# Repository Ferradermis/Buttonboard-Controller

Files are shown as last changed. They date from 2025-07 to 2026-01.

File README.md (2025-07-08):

# FRC Custom Operator Control Board
## Overview
This project provides a reusable hardware and software ecosystem for rapidly developing game-specific control surfaces for FIRST Robotics Competition (FRC) teams. Inspired by successful world-class teams who have leveraged custom control boards for years, our solution enables any team to quickly create and deploy specialized operator interfaces tailored to each year's unique game challenges.

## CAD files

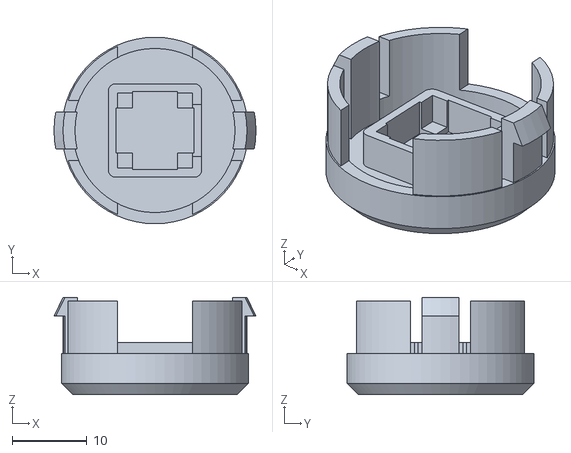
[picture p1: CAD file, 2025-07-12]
button/buttonface thicker.stl
27.0 x 24.9 x 13.0

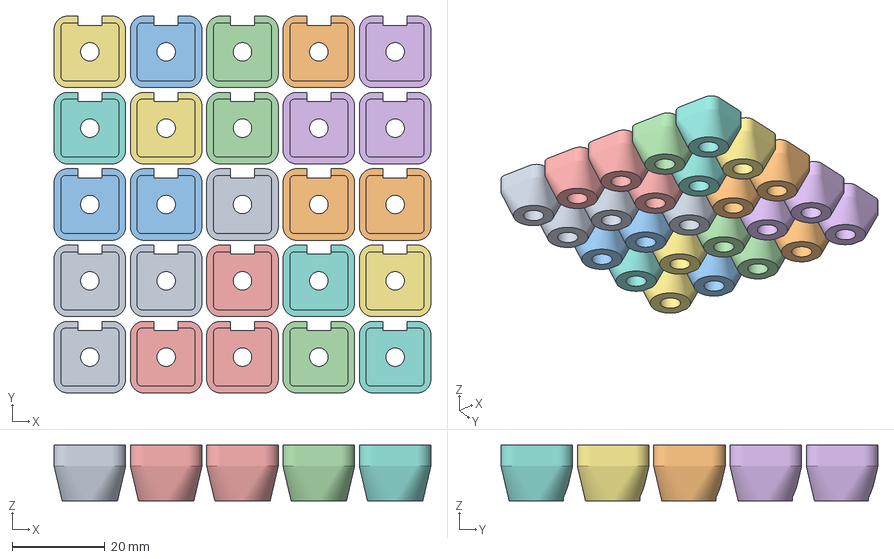
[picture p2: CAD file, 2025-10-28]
button2/ledcap.3mf
81.5 x 81.5 x 12.0 mm
ledcap.stl x 25

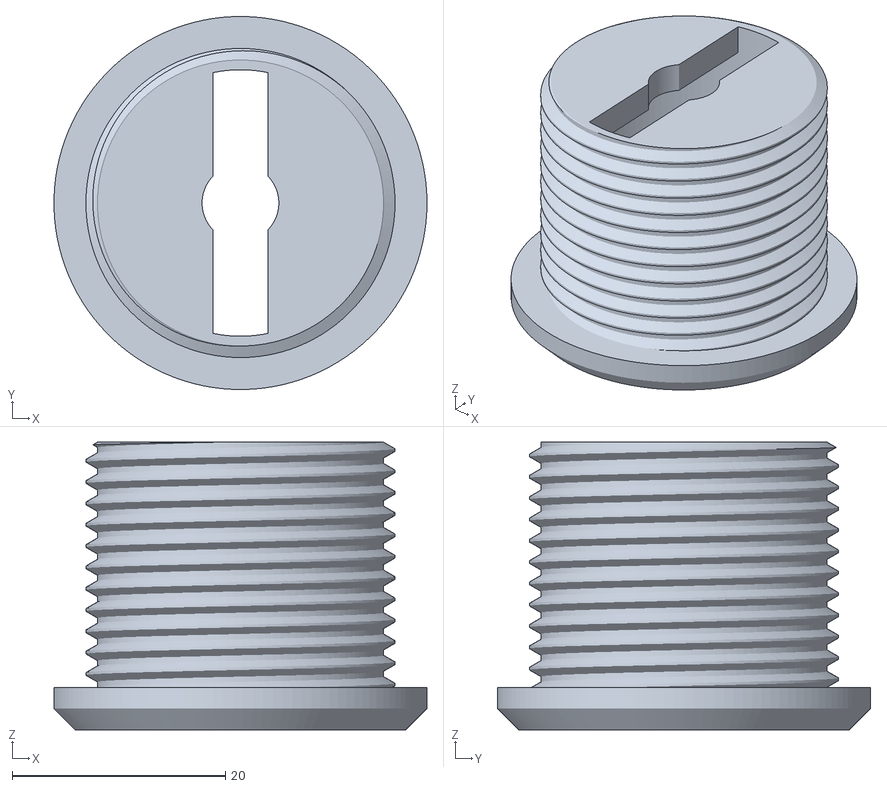
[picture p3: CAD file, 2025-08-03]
button3/housing.stl
35.0 x 35.0 x 27.0

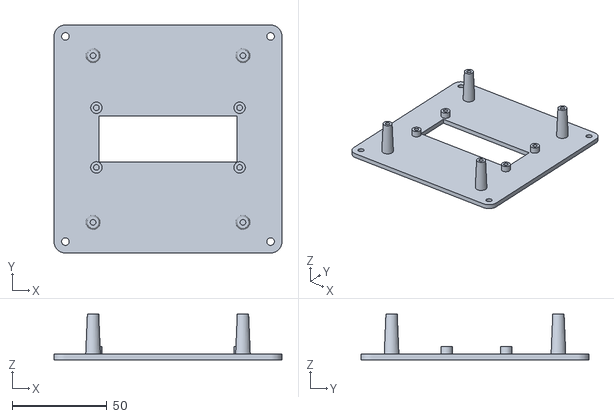
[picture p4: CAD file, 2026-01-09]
pcb chassis/chassis.stl
120.0 x 120.0 x 24.0

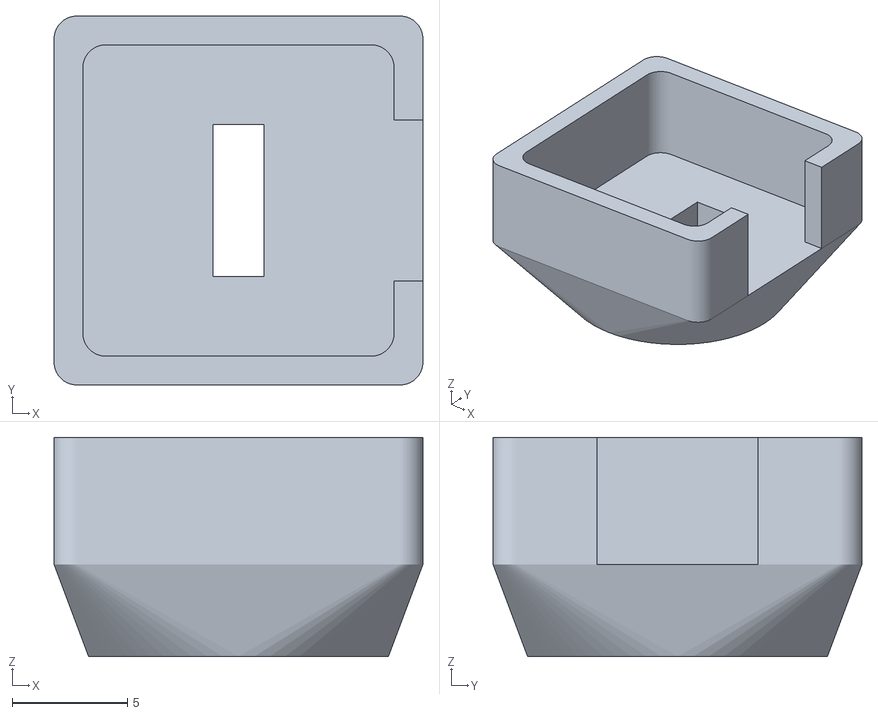
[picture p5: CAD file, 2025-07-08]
button/cap.stl
16.0 x 16.0 x 9.50

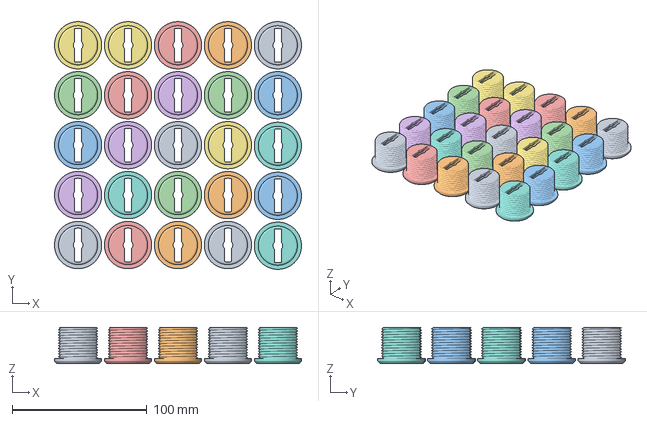
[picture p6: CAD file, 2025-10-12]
button2/housing.3mf
183.0 x 183.5 x 27.0 mm
housing.stl x 25

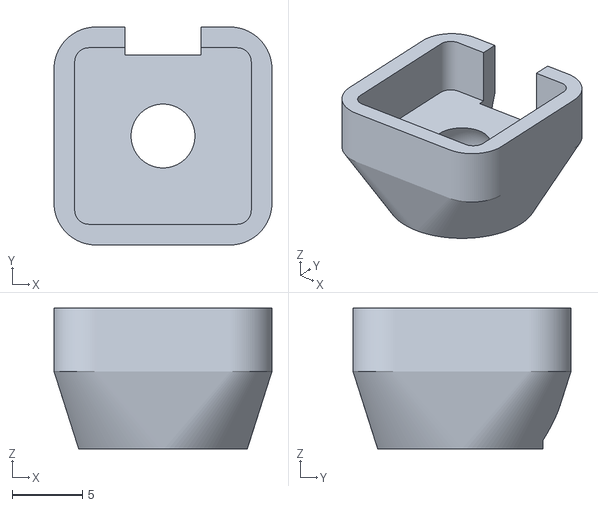
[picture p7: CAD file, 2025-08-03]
button3/ledcap.stl
15.5 x 15.5 x 10.0

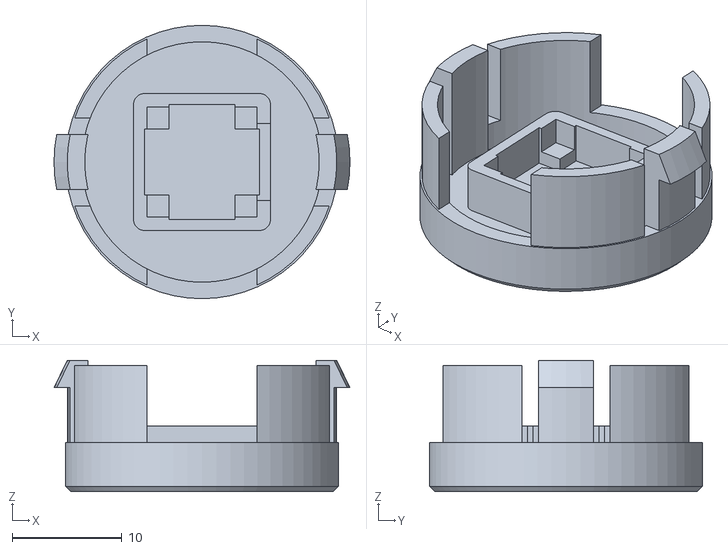
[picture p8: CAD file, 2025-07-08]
button/buttonface.stl
27.0 x 24.9 x 12.0

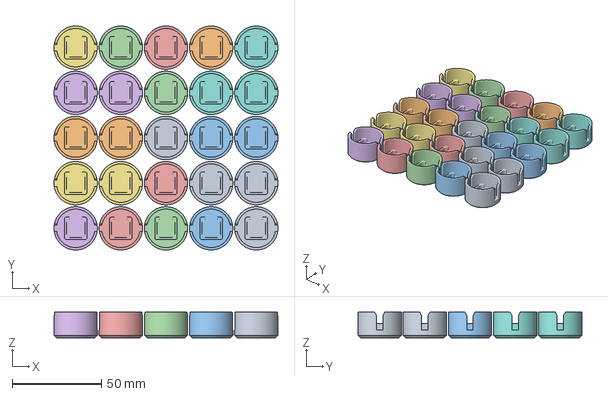
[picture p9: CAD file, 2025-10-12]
button2/button.3mf
125.2 x 125.2 x 14.5 mm
button.stl x 25

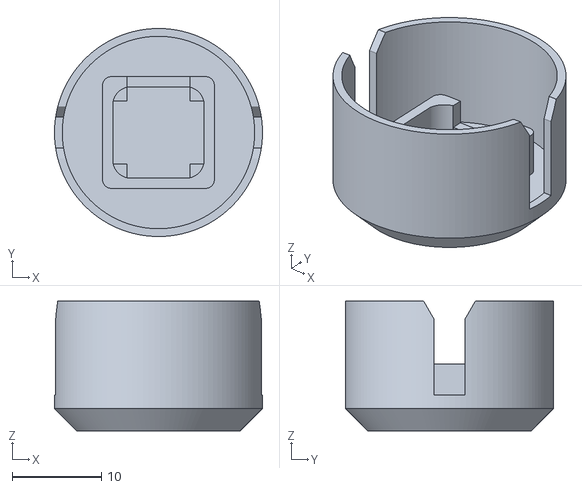
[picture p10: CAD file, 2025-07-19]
button3/button.stl
23.2 x 23.2 x 14.5

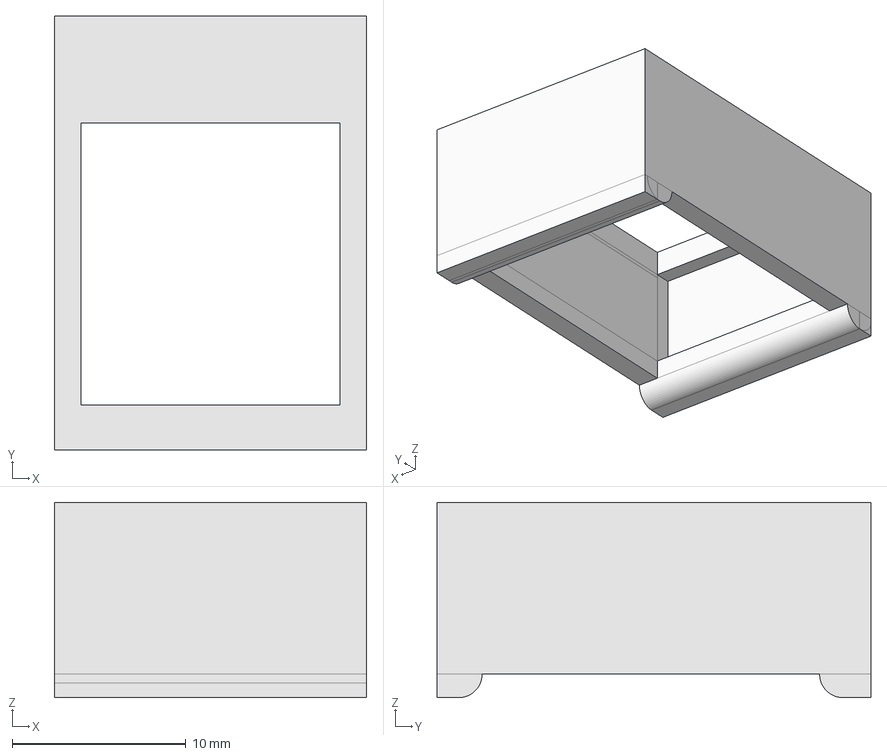
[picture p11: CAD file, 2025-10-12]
button2/rj45_keystone_receiver.step
18.0 x 25.0 x 11.2 mm

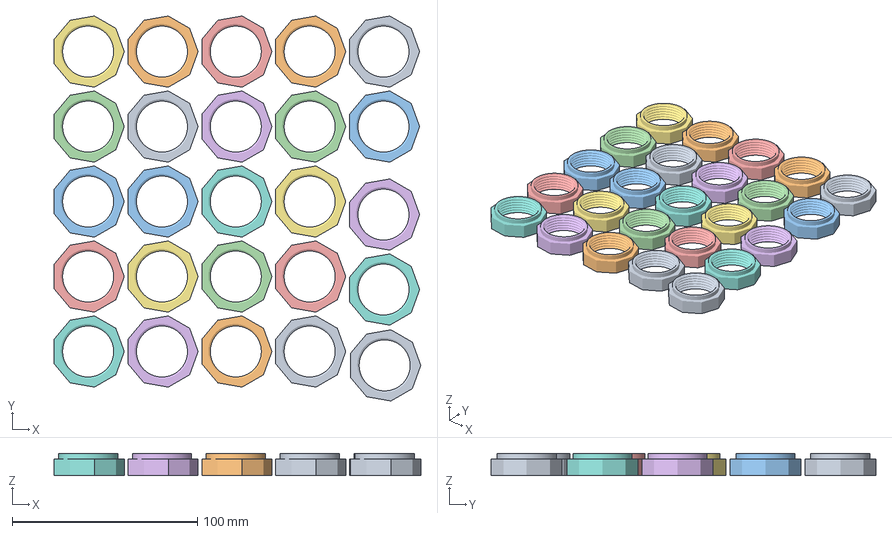
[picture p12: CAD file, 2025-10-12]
button2/nut.3mf
197.8 x 207.7 x 12.0 mm
nut.stl 1
nut.stl 3
nut.stl 4
nut.stl 5
nut.stl 6
nut.stl 8
nut.stl 9
nut.stl 10
nut.stl 11
nut.stl 12
nut.stl 13
nut.stl 15
nut.stl 16
nut.stl 17
nut.stl 18
nut.stl 19
nut.stl 20
nut.stl 21
nut.stl 22
nut.stl 24
nut.stl 25
nut.stl 26
nut.stl 27
nut.stl 31
nut.stl 33

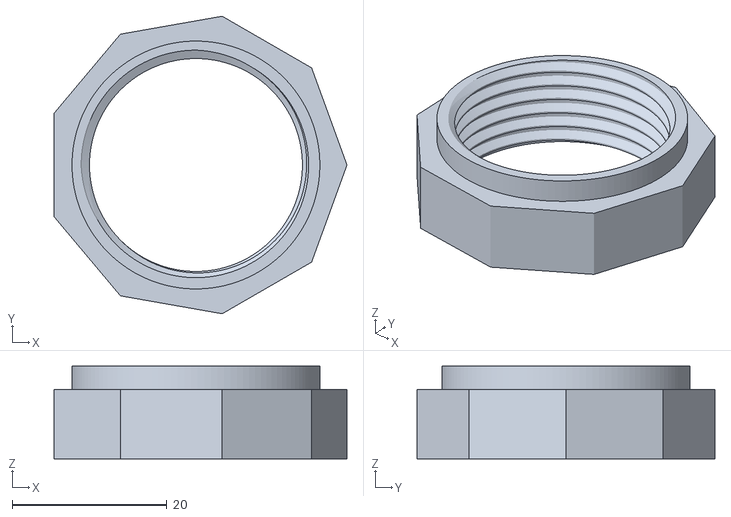
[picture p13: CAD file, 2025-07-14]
button3/nut.stl
37.8 x 38.4 x 12.0

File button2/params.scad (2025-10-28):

echo("including params.scad");
include <./ISOThread.scad>
$fn=117;

//housing params (including threads)
thread_tolerance=0.25;
od_rim=35;
h_rim=4;
bevel_rim=2;
tpitch=2.0;
od_housing=29;
od_housing_minor=tpitch;
od_housing_wings=30;
id_housing=25;
h_housing=27;
w_housing_guide=2;

w_fin=1.2;
h_fin=6;

//button params
od_button=24.25;
id_button=21.50;
t_buttonface=3.5;
bevel_buttonface=1.5;
h_button=14.5;
h_button_travel=h_button+2;
w_button_guide=3.5;

//switch params
d_switch_key=6.05;
h_switch_key=3.5;
d_switch_neck=7;
d_switch_body=7.20;
d_switch_shoulder=12;



w_wire_notch=d_switch_body-2;



w_pixel_board=10.2;
w_pixel=7;
t_pixel=1;
t_pixel_unit=4.25;
w_pedestal=12.5;
h_pedestal=t_pixel_unit + 0.25;

h_nut=9;
d_nut=od_housing+10;
nut_sides=9;
h_nut_rim=3;

h_led_cap=12;
w_led_cap=w_pedestal+3;


module rcube(s,r=1){
    hull(){
        for(x=[r,s[0]-r])
            for(y=[r,s[1]-r])
                translate([x,y,0])
                    cylinder(r=r,h=s[2]);
    }
}

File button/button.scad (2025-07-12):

$fn=60;

d_button=24.95;
d_minor=24.6;

t_total=12.56;
l_tab=4;

t_bevel=1.5;
    t_face=t_bevel+1.5;
    h_face=4;
    t_shell=1.5;


main();

//cap();

//clip_shape();

module cap(){
    cap_size=16;
    cap_base_d=13;
    cap_height=9.5;
    cap_stem_height=4;
    cap_cavity_size=13.5;
    difference(){
        union(){
            hull(){
                cylinder(d=cap_base_d,h=1);
                translate([-cap_size/2,-cap_size/2,cap_stem_height])
                    rcube([16,16,cap_height-cap_stem_height]);
            }
        }
        union(){
            translate([-cap_cavity_size/2,-cap_cavity_size/2,cap_stem_height])
                    rcube([cap_cavity_size,cap_cavity_size,15]);

            //button slot
            translate([-1.1,-3.3,0])
                cube([2.2,6.6,14]);
            //notch for wires
            translate([0,-3.5,cap_stem_height])
                cube([10,7,10]);
            
        }
    }
}


module clip_shape(){
    translate([d_minor/2-1.6,.5+t_bevel])
    polygon(points=[
        [0,0],
        [1.6,0],
        [1.6,8.5],
        [2.81,8.5],
        [1.6,11],
        [0,11]

    ]);
}

module main(){
    


    difference(){
        union(){
            cylinder(d1=d_button-t_bevel*2,d2=d_button,h=t_bevel);
            translate([0,0,t_bevel])
                cylinder(d=d_button,h=h_face);
        }
        union(){
            translate([0,0,t_face])
                cylinder(d=d_button-t_shell*2,h=h_face);
        }
    }

    difference(){
        union(){
            translate([0,0,t_bevel])
                cylinder(d=d_minor,h=11);
        }
        union(){
            translate([-20,-4,4.5])
                cube([40,8,20]);

            translate([-5,-20,4.5])
                cube([10,40,20]);

            cylinder(d=d_button - 2*t_shell, h=20);
        }
    }

    pixel_holder_size=12.5;
    
    difference(){
        union(){
            translate([-pixel_holder_size/2,-pixel_holder_size/2,0])
                rcube([pixel_holder_size,pixel_holder_size,t_face+4]);
        }
        union(){
            translate([0,-3.5,4])
                cube([10,7,10]);

            translate([-5.25,-3,2.5])
                cube([10.5,6,10]);
            translate([-3,-5.25,2.5])
                cube([6,10.5,10]);
            
            translate([-5,-5,3.7])
                cube([10,10,10]);
                
        }
    }

    intersection(){
        translate([-20,-2.5,0])
            cube([40,5,40]);
        rotate_extrude(){
            clip_shape();
        }
    }
    
}

module rcube(size,r=1){
    hull(){
        for(x=[r,size[0]-r])
            for (y=[r,size[1]-r])
                translate([x,y,0])
                    cylinder(r=r,h=size[2]);
    }
            
}

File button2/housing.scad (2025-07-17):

include <./params.scad>



main();

module main(){
    difference(){
        union(){
            iso_thread(m=od_housing,l=h_housing,p=tpitch);
            cylinder(d1=od_rim-2*bevel_rim,d2=od_rim,h=bevel_rim);
            translate([0,0,bevel_rim])
                cylinder(d=od_rim,h=h_rim-bevel_rim);

            

        }
        union(){

            cylinder(d=id_housing,h=h_housing-3);

            cylinder(d=d_switch_body,h=h_housing);

            intersection(){
                cylinder(d=id_housing,h=h_housing);
                translate([-w_wire_notch/2,-od_housing/2,0])
                    cube([w_wire_notch,od_housing,h_housing]);

            }

        }
    }

    


    //button guides
    difference(){
        union(){
            intersection(){
                cylinder(d=id_housing,h=h_housing);
                translate([-od_housing/2,-w_housing_guide/2,0])
                    cube([od_housing,w_housing_guide,h_housing]);
            }
        }
        union(){
            cylinder(d=id_housing,h=4);
            translate([0,0,4])
                cylinder(d1=id_housing,d2=id_housing-2 * w_housing_guide,h=w_housing_guide);
            cylinder(d=id_housing-2 * w_housing_guide,h=h_housing);
        }
    }

}

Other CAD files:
button3/params.scad
button2/button.stl
button2/ledcap.scad
button2/ledcap.stl
button2/rj45_keystone_receiver.scad
button3/ISOThread.scad
button3/button.scad
button3/housing.scad
button3/ledcap.scad
button3/nut.scad
button3/socket.scad
pcb chassis/chassis.scad

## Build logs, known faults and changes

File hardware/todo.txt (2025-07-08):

Add ethernet jack - done
add USB port to board - done
add reset MCU pins/button - done
add USB Host port - done
instead of 4 GPIOs, add 4 more buttons (kids got to 24 FAST) - done

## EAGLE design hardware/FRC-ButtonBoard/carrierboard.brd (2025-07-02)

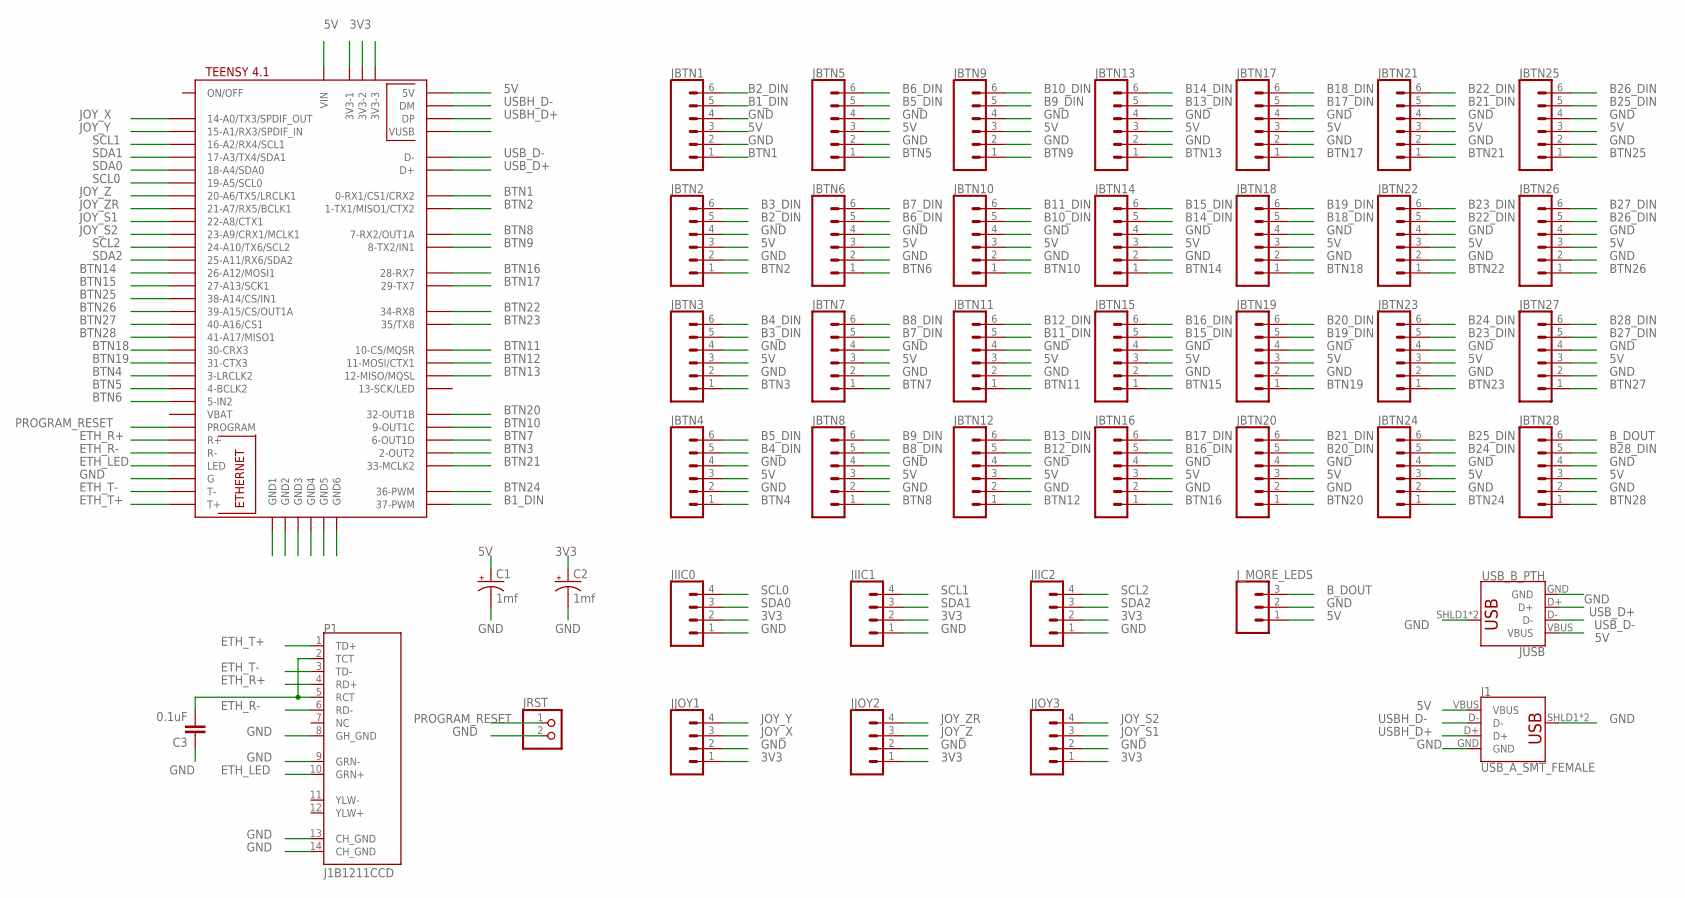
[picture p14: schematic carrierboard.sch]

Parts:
C1, C2: 1mf; CPOL-RADIAL-5MM-10MM-KIT
C3: 0.1uF; CAP-PTH-SMALL-KIT
J1: USB_A_SMT_FEMALE; USB-A-S-SILK-FEMALE
JBTN1, JBTN2, JBTN3, JBTN4, JBTN5, JBTN6, JBTN7, JBTN8, JBTN9, JBTN10, JBTN11, JBTN12, JBTN13, JBTN14, JBTN15, JBTN16, JBTN17, JBTN18, JBTN19, JBTN20, JBTN21, JBTN22, JBTN23, JBTN24, JBTN25, JBTN26, JBTN27, JBTN28: CONN_06SILK_FEMALE_PTH; 1X06
JIIC0, JIIC1, JIIC2: CONN_04POLAR; MOLEX-1X4
JJOY1, JJOY2, JJOY3: CONN_04LONGPADS; 1X04_LONGPADS
JRST: PINHD-1X2; 1X02
JUSB: USB_B_PTH; USB-B-PTH
J_MORE_LEDS: CONN_03LONGPADS; 1X03_LONGPADS
P1: J1B1211CCD
U$1: TEENSY41

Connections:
3V3: C2.+, JIIC0.2, JIIC1.2, JIIC2.2, JJOY1.1, JJOY2.1, JJOY3.1, U$1.3V3-1, U$1.3V3-2, U$1.3V3-3
5V: C1.+, J1.VBUS, JBTN1.3, JBTN2.3, JBTN3.3, JBTN4.3, JBTN5.3, JBTN6.3, JBTN7.3, JBTN8.3, JBTN9.3, JBTN10.3, JBTN11.3, JBTN12.3, JBTN13.3, JBTN14.3, JBTN15.3, JBTN16.3, JBTN17.3, JBTN18.3, JBTN19.3, JBTN20.3, JBTN21.3, JBTN22.3, JBTN23.3, JBTN24.3, JBTN25.3, JBTN26.3, JBTN27.3, JBTN28.3, JUSB.VBUS, J_MORE_LEDS.1, U$1.+5V (5V), U$1.VIN
B1_DIN: JBTN1.5, U$1.37-PWM
B2_DIN: JBTN1.6, JBTN2.5
B3_DIN: JBTN2.6, JBTN3.5
B4_DIN: JBTN3.6, JBTN4.5
B5_DIN: JBTN4.6, JBTN5.5
B6_DIN: JBTN5.6, JBTN6.5
B7_DIN: JBTN6.6, JBTN7.5
B8_DIN: JBTN7.6, JBTN8.5
B9_DIN: JBTN8.6, JBTN9.5
B10_DIN: JBTN9.6, JBTN10.5
B11_DIN: JBTN10.6, JBTN11.5
B12_DIN: JBTN11.6, JBTN12.5
B13_DIN: JBTN12.6, JBTN13.5
B14_DIN: JBTN13.6, JBTN14.5
B15_DIN: JBTN14.6, JBTN15.5
B16_DIN: JBTN15.6, JBTN16.5
B17_DIN: JBTN16.6, JBTN17.5
B18_DIN: JBTN17.6, JBTN18.5
B19_DIN: JBTN18.6, JBTN19.5
B20_DIN: JBTN19.6, JBTN20.5
B21_DIN: JBTN20.6, JBTN21.5
B22_DIN: JBTN21.6, JBTN22.5
B23_DIN: JBTN22.6, JBTN23.5
B24_DIN: JBTN23.6, JBTN24.5
B25_DIN: JBTN24.6, JBTN25.5
B26_DIN: JBTN25.6, JBTN26.5
B27_DIN: JBTN26.6, JBTN27.5
B28_DIN: JBTN27.6, JBTN28.5
BTN1: JBTN1.1, U$1.0-RX1/CS1/CRX2
BTN2: JBTN2.1, U$1.1-TX1/MISO1/CTX2
BTN3: JBTN3.1, U$1.2-OUT2
BTN4: JBTN4.1, U$1.3-LRCLK2
BTN5: JBTN5.1, U$1.4-BCLK2
BTN6: JBTN6.1, U$1.5-IN2
BTN7: JBTN7.1, U$1.6-OUT1D
BTN8: JBTN8.1, U$1.7-RX2/OUT1A
BTN9: JBTN9.1, U$1.8-TX2/IN1
BTN10: JBTN10.1, U$1.9-OUT1C
BTN11: JBTN11.1, U$1.10-CS\MQSR (10-CS/MQSR)
BTN12: JBTN12.1, U$1.11-MOSI/CTX1
BTN13: JBTN13.1, U$1.12-MISO/MQSL
BTN14: JBTN14.1, U$1.26-A12/MOSI1
BTN15: JBTN15.1, U$1.27-A13/SCK1
BTN16: JBTN16.1, U$1.28-RX7
BTN17: JBTN17.1, U$1.29-TX7
BTN18: JBTN18.1, U$1.30-CRX3
BTN19: JBTN19.1, U$1.31-CTX3
BTN20: JBTN20.1, U$1.32-OUT1B
BTN21: JBTN21.1, U$1.33-MCLK2
BTN22: JBTN22.1, U$1.34-RX8
BTN23: JBTN23.1, U$1.35-TX8 (35/TX8)
BTN24: JBTN24.1, U$1.36-PWM
BTN25: JBTN25.1, U$1.38-A14/CS/IN1
BTN26: JBTN26.1, U$1.39-A15/CS/OUT1A
BTN27: JBTN27.1, U$1.40-A16/CS1
BTN28: JBTN28.1, U$1.41-A17/MISO1
B_DOUT: JBTN28.6, J_MORE_LEDS.3
ETH_LED: P1.10 (GRN+), U$1.LED
ETH_R+: P1.4 (RD+), U$1.R+
ETH_R-: P1.6 (RD-), U$1.R-
ETH_T+: P1.1 (TD+), U$1.T+
ETH_T-: P1.3 (TD-), U$1.T-
GND: C1.-, C2.-, C3.1, J1.GND, J1.SHLD1 (SHIELD), J1.SHLD2 (SHIELD), JBTN1.2, JBTN1.4, JBTN2.2, JBTN2.4, JBTN3.2, JBTN3.4, JBTN4.2, JBTN4.4, JBTN5.2, JBTN5.4, JBTN6.2, JBTN6.4, JBTN7.2, JBTN7.4, JBTN8.2, JBTN8.4, JBTN9.2, JBTN9.4, JBTN10.2, JBTN10.4, JBTN11.2, JBTN11.4, JBTN12.2, JBTN12.4, JBTN13.2, JBTN13.4, JBTN14.2, JBTN14.4, JBTN15.2, JBTN15.4, JBTN16.2, JBTN16.4, JBTN17.2, JBTN17.4, JBTN18.2, JBTN18.4, JBTN19.2, JBTN19.4, JBTN20.2, JBTN20.4, JBTN21.2, JBTN21.4, JBTN22.2, JBTN22.4, JBTN23.2, JBTN23.4, JBTN24.2, JBTN24.4, JBTN25.2, JBTN25.4, JBTN26.2, JBTN26.4, JBTN27.2, JBTN27.4, JBTN28.2, JBTN28.4, JIIC0.1, JIIC1.1, JIIC2.1, JJOY1.2, JJOY2.2, JJOY3.2, JRST.2, JUSB.GND, JUSB.SHLD1 (SHIELD), JUSB.SHLD2 (SHIELD), J_MORE_LEDS.2, P1.8 (GH_GND), P1.9 (GRN-), P1.13 (CH_GND), P1.14 (CH_GND), U$1.G, U$1.GND1, U$1.GND2, U$1.GND3, U$1.GND4, U$1.GND5, U$1.GND6
JOY_S1: JJOY3.3, U$1.22-A8/CTX1
JOY_S2: JJOY3.4, U$1.23-A9/CRX1/MCLK1
JOY_X: JJOY1.3, U$1.14-A0/TX3/SPDIF_OUT
JOY_Y: JJOY1.4, U$1.15-A1/RX3/SPDIF_IN
JOY_Z: JJOY2.3, U$1.20-A6/TX5/LRCLK1
JOY_ZR: JJOY2.4, U$1.21-A7/RX5/BCLK1
unnamed: C3.2, P1.2 (TCT), P1.5 (RCT)
PROGRAM_RESET: JRST.1, U$1.PROGRAM
SCL0: JIIC0.4, U$1.19-A5/SCL0
SCL1: JIIC1.4, U$1.16-A2/RX4/SCL1
SCL2: JIIC2.4, U$1.24-A10/TX6/SCL2
SDA0: JIIC0.3, U$1.18-A4/SDA0
SDA1: JIIC1.3, U$1.17-A3/TX4/SDA1
SDA2: JIIC2.3, U$1.25-A11/RX6/SDA2
USBH_D+: J1.D+, U$1.DP
USBH_D-: J1.D-, U$1.DM
USB_D+: JUSB.D+, U$1.D+
USB_D-: JUSB.D-, U$1.D-

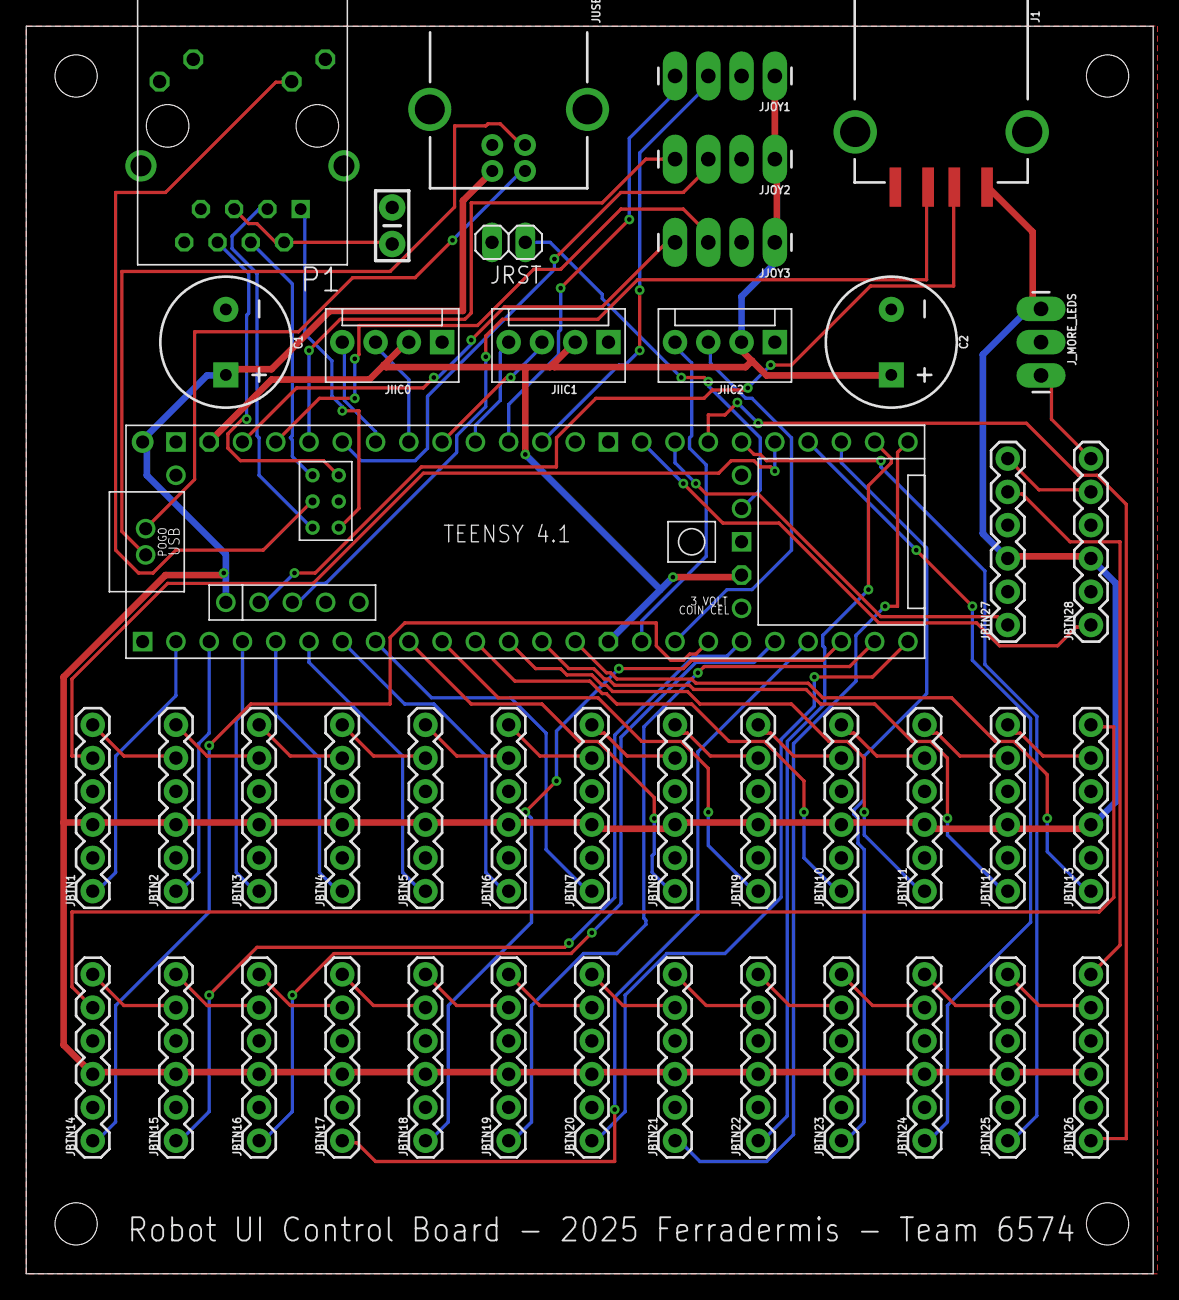
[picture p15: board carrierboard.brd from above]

Board: 2 copper layers, 86.0 x 95.2 mm, 43 parts (0 on the bottom side), 83 nets.

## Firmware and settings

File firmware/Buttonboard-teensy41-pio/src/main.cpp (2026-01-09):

// Add this to the top of your main.cpp (after other includes)
#include "TeensyUDPClient.h"
#include "NativeEthernet.h"
#include <Bounce2.h>
#include <FastLED.h>
#include <IntervalTimer.h>
#include <Wire.h>
#include <LiquidCrystal_I2C.h>


#pragma region Button Pins
#define PIN_BTN_01 0
#define PIN_BTN_02 1
#define PIN_BTN_03 2
#define PIN_BTN_04 3
#define PIN_BTN_05 4
#define PIN_BTN_06 5
#define PIN_BTN_07 6
#define PIN_BTN_08 7
#define PIN_BTN_09 8
#define PIN_BTN_10 9
#define PIN_BTN_11 10
#define PIN_BTN_12 11
#define PIN_BTN_13 12
#define PIN_BTN_14 26
#define PIN_BTN_15 27
#define PIN_BTN_16 28
#define PIN_BTN_17 29
#define PIN_BTN_18 30
#define PIN_BTN_19 31
#define PIN_BTN_20 32
#define PIN_BTN_21 33
#define PIN_BTN_22 34
#define PIN_BTN_23 35
#define PIN_BTN_24 36
#define PIN_BTN_25 38
#define PIN_BTN_26 39
#define PIN_BTN_27 40
#define PIN_BTN_28 41
#pragma endregion

#pragma region Joystick Axis Pins
#define PIN_JOY_X 14
#define PIN_JOY_Y 15
#define PIN_JOY_Z 20
#define PIN_JOY_ZR 21
#define PIN_JOY_S1 22
#define PIN_JOY_S2 23
#pragma endregion


#define PIN_LED 13
#define NUM_LEDS 23
#define DATA_PIN 37
#define STATES_PER_LED 4 // Each LED can have 8 animation states (on/off, or different colors)


const uint8_t _buttonPins[] = {
  PIN_BTN_01,PIN_BTN_02,PIN_BTN_03,PIN_BTN_04,PIN_BTN_05,PIN_BTN_06,
  PIN_BTN_07,PIN_BTN_08,PIN_BTN_09,PIN_BTN_10,PIN_BTN_11,PIN_BTN_12,
  PIN_BTN_13,PIN_BTN_14,PIN_BTN_15,PIN_BTN_16,PIN_BTN_17,PIN_BTN_18,
  PIN_BTN_19,PIN_BTN_20,PIN_BTN_21,PIN_BTN_22,PIN_BTN_23,PIN_BTN_24,
  PIN_BTN_25,PIN_BTN_26,PIN_BTN_27,PIN_BTN_28
};

const uint8_t numButtons = 23; //sizeof(_buttonPins) / sizeof(_buttonPins[0]);



Bounce buttons[numButtons];

CRGB leds[NUM_LEDS];
CRGB noopColor= CRGB::Black; // Default noop color
CRGB allianceColor = CRGB::Black; // Default alliance color
CRGB redAllianceColors[STATES_PER_LED]={CRGB::DarkRed, CRGB::Red, CRGB::DarkRed, CRGB::Black};
CRGB blueAllianceColors[STATES_PER_LED]={CRGB::DarkBlue, CRGB::Blue, CRGB::DarkBlue, CRGB::Black};
CRGB algaeColor=CRGB::SeaGreen;



void SetupEthernet();
void SetLEDColors(int ledIndex, std::initializer_list<CRGB> colors);
void SetLEDColor(int ledIndex, CRGB color);
void CheckButtonStates();
void transferColors();
void SetLEDColorFromTagId(int tagId, CRGB color);
void SetLEDColorFromTagIdLeft(int tagId, CRGB color);
void SetLEDColorFromTagIdRight(int tagId, CRGB color);

void isr_animationTimer();
volatile uint8_t animationFrame = 0; // Animation frame counter
IntervalTimer animationTimer; // Timer for animations

CRGB ledStates[NUM_LEDS * STATES_PER_LED];



TeensyUDPClient udpClient(6574);// Your team number

LiquidCrystal_I2C lcd(0x27, 16, 2);

uint32_t LastBatteryCheck=0;

bool foundATag=false;
bool bAutoScoring=false;
bool bAutomated=false;
bool bTeleop=false;
bool bMatchTimeCountingDown=false;
float lastMatchTime=0.0;

// In your setup() function, replace the NetworkTables setup with:
void setup() {

    Wire.begin();
    // Initialize the LCD
    lcd.init();
    // Turn on the backlight
    lcd.backlight();
    
    
    Serial.begin(115200);
    while (!Serial && (millis() < 5000)) ; // wait for Serial to initialize (with timeout for non-USB serial)
    Serial.println("Buttonboard starting up...");
    lcd.setCursor(0, 0);  // Column 0, Row 0
    lcd.print("Ferra Bttn Board");
    
    FastLED.addLeds<NEOPIXEL, DATA_PIN>(leds, NUM_LEDS);
    FastLED.setBrightness(192);
    FastLED.clear();
    FastLED.showColor(CRGB::DarkRed);


    for (int i=0;i<numButtons;i++) {
        buttons[i].attach(_buttonPins[i], INPUT_PULLUP);
        buttons[i].interval(50); // 50ms debounce interval
    }


    pinMode(PIN_LED, OUTPUT);
    digitalWrite(PIN_LED, HIGH); 
    
    if(digitalRead(PIN_BTN_23)==HIGH){

        lcd.setCursor(0, 1);  // Column 0, Row 1
        lcd.print("Ethernet Startup");
        SetupEthernet();
        lcd.setCursor(0, 1);  // Column 0, Row 1
        lcd.print("Ethernet Started");
        lcd.setCursor(0, 0);
        lcd.print(String(Ethernet.localIP()[0]));
        lcd.print(".");
        lcd.print(String(Ethernet.localIP()[1]));
        lcd.print(".");
        lcd.print(String(Ethernet.localIP()[2]));
        lcd.print(".");
        lcd.print(String(Ethernet.localIP()[3]));
        lcd.print("         "); 
    }
    else{
        lcd.setCursor(0, 1);  // Column 0, Row 1
        lcd.print("Ethernet SKIPPED");
    }

    delay(1500); // Let ethernet stabilize
    lcd.setCursor(0, 1);  // Column 0, Row 1
    lcd.print("Start UDP Client");

    if (udpClient.begin()) {
        Serial.println("🎉 UDP client ready!");
        
        lcd.setCursor(0, 1);  // Column 0, Row 1
        lcd.print("UDP client ready!");
        

    }
    else {
        Serial.println("❌ UDP client failed to start");
        lcd.setCursor(0, 1);  // Column 0, Row 1
        lcd.print("UDP Failure     ");
    }

    // Initialize the OverlappingLEDManager
    for (int i=0;i<NUM_LEDS * STATES_PER_LED;i++) {
        ledStates[i] = CRGB::Black; // Initialize all states to off
    }
    
    
    animationTimer.begin(isr_animationTimer, 200000); // 500ms interval for animation toggle

    

    //yeah this is our throw-away color.  The SetLEDColors function will ignore this color and leave the LED unchanged.
    noopColor.setRGB(1,2,3); 
    Joystick.X(512);
    Joystick.Y(512);   
    Joystick.Z(512);
    Joystick.Zrotate(512);
    Joystick.slider(512);
    Joystick.sliderLeft(512);
    Joystick.sliderRight(512);

    digitalWrite(PIN_LED, LOW);
}


void loop() {

    //check for messages from robot
    udpClient.update();
    // If anything has changed, update the state of the control board.
    if (udpClient.hasChangedData()) {

        foundATag=((udpClient.getLeftCamTagID()>0) || (udpClient.getRightCamTagID()>0));
        if (foundATag) {
            Serial.print("Left Tag ");
            Serial.println(udpClient.getLeftCamTagID());
            Serial.print("Right Tag");
            Serial.println(udpClient.getRightCamTagID());

            lcd.setCursor(0, 1);  // Column 0, Row 1
            lcd.print("Tags:");
            lcd.print(udpClient.getLeftCamTagID());

            
            lcd.print(",");
            lcd.print(udpClient.getRightCamTagID());

           if (!bAutoScoring){
            for(int i=0;i<12;i++)
            {
                SetLEDColor(i,CRGB::Black);
            }
                SetLEDColorFromTagIdLeft(udpClient.getLeftCamTagID(),CRGB::Green);
                SetLEDColorFromTagIdRight(udpClient.getRightCamTagID(),CRGB::Green);
           }
           transferColors();
           FastLED.show();
           Serial.println("TAG FOUND");
        }
        else{
            for(int i=0;i<12;i++)
            {
                SetLEDColor(i,CRGB::Black);
            }
            transferColors();
           FastLED.show();
            Serial.println("TAG NOT FOUND");
        }


        if (udpClient.getAllianceColor() =="blue") {
            allianceColor = CRGB::Blue;
        } else if (udpClient.getAllianceColor() =="red") {
            allianceColor = CRGB::Red;
        }
        else{
            allianceColor = CRGB::Black; // Default if no alliance color set
        }

        if (udpClient.getMatchTimeRemaining()==-1.0){
            bMatchTimeCountingDown=false;
        } else if (udpClient.getMatchTimeRemaining()<lastMatchTime){
            bMatchTimeCountingDown=true;
        }
        lastMatchTime=udpClient.getMatchTimeRemaining();

        if (udpClient.getRobotMode()!="Teleop") {
            
                bAutomated=true;
                bMatchTimeCountingDown=false;
        }
        else{
            if (bAutomated){
                bAutomated=false;
                for(int i=0;i<numButtons;i++)
                {
                    SetLEDColor(i, CRGB::Black);
                }
            }

            if(udpClient.getMatchTimeRemaining()<=21.0 && bMatchTimeCountingDown){
                SetLEDColors(22, {CRGB::Red, CRGB::Black, CRGB::Red, CRGB::Black});
            }

        }
        


    }
    
    bAutomated=false;
    if (bAutomated){
        if (udpClient.getAllianceColor() =="blue") {
            for(int i=0;i<numButtons;i++)
            {
                SetLEDColor(i, blueAllianceColors[(animationFrame + i) % STATES_PER_LED]); // Stagger animation by button index
            }
        } else if (udpClient.getAllianceColor() =="red") {
            for(int i=0;i<numButtons;i++)
            {
                SetLEDColor(i, redAllianceColors[(animationFrame + i) % STATES_PER_LED]); // Stagger animation by button index
            }
        }
        else{
            for(int i=0;i<numButtons;i++)
            {
                SetLEDColor(i, CRGB::Black);
            }
        }
    }

    
        CheckButtonStates();
    
            


    //update the LED colors according to current animation frame

    transferColors();

    FastLED.show();

    delay(0);
}

void transferColors(){
    noInterrupts();
    for (int i = 0; i < NUM_LEDS; i++) {
        // Update each LED based on its current state
        CRGB currentColor = ledStates[i * STATES_PER_LED + animationFrame];
        FastLED.leds()[i] = currentColor;
    }
    interrupts();
}

void CheckButtonStates() {
    bool warning=false;
    for (uint8_t i = 0; i < numButtons; i++) {
    buttons[i].update();
    if (buttons[i].fell()) {
        if(bAutomated){
            //warning=true;
            //break;
        }
      //set PIN 13 LED for debug purposes
      digitalWrite(PIN_LED, HIGH);

      //set USB joystick button state
      Joystick.button(i+1,true);

      //set reef buttons to black, then set THIS reef button to purple.
      if (i<12){
        for(int j=0;j<12;j++){
            SetLEDColors(j, {CRGB::Black, noopColor, CRGB::Black, noopColor});
          
        }
        SetLEDColors(i, {CRGB::Purple, noopColor, CRGB::Purple, noopColor});
      }

      if (i>=12 && i<16){
        for (int j=12;j<16;j++){
            SetLEDColor(j,CRGB::Black);
        }
        SetLEDColor(i,CRGB::Purple);
      }

      
      if (i>=16 && i<22){
        //set level buttons to black, then set THIS level button to purple.
        for(int j=16;j<22;j++){

            SetLEDColor(j, CRGB::Black);
          
        }
        switch(i){
            case 16:
                SetLEDColor(i, CRGB::Blue);
                break;
            case 17:
                SetLEDColor(i, algaeColor);
                break;
            case 18:
                SetLEDColor(i, algaeColor);
                break;
            case 19:
                SetLEDColor(i, CRGB::Yellow);
                break;
            case 20:
                SetLEDColor(i, CRGB::Orange);
                break;
            case 21:
                SetLEDColor(i, CRGB::Purple);
                break;
        }

      }



      
    }
      
    if(buttons[i].rose()){
      // If the button is released, turn off the LED
      digitalWrite(PIN_LED, LOW);

      //set the USB joystick button state to released
      Joystick.button(i+1,false);
    }
  }
    if (warning){
    //if we're automated, just turn off all buttons
            for(int i=0;i<numButtons;i++)
            {
                SetLEDColor(i, CRGB::Orange);
                
            }
            transferColors();
            FastLED.show();
            delay(50);
            for(int i=0;i<numButtons;i++)
            {
                SetLEDColor(i, CRGB::Black);
                
            }
            transferColors();
            FastLED.show();
            delay(50);
            for(int i=0;i<numButtons;i++)
            {
                SetLEDColor(i, CRGB::Orange);
                
            }
            transferColors();
            FastLED.show();
            delay(50);
            for(int i=0;i<numButtons;i++)
            {
                SetLEDColor(i, CRGB::Black);
                
            }
            transferColors();
            FastLED.show();
            
        }
}





void SetLEDColors(int ledIndex, std::initializer_list<CRGB> colors) {
    if (ledIndex < 0 || ledIndex >= NUM_LEDS) return; // Out of bounds
    
    int i = 0;
    for (const CRGB& color : colors) {
        if (i >= STATES_PER_LED) break; // Don't exceed array bounds
        if (color == noopColor) {
            // If color is noop, ignore
        } else {
            // Otherwise, set to the specified color
            ledStates[ledIndex * STATES_PER_LED + i] = color;
        }
        i++;
    }
    
}

void SetLEDColor(int ledIndex, CRGB color) {
    if (ledIndex < 0 || ledIndex >= NUM_LEDS) return; // Out of bounds
    for (int i = 0; i < STATES_PER_LED; i++) {
        ledStates[ledIndex * STATES_PER_LED + i] = color;
    }
    
}



void SetLEDColorFromTagIdRight(int tagId, CRGB color){
    switch(tagId){
        case 21:
        case 10:
            SetLEDColor(0,CRGB::Green);
            //SetLEDColor(1,CRGB::Green);
            break;
        case 22:
        case 9:
            SetLEDColor(2,CRGB::Green);
            //SetLEDColor(3,CRGB::Green);
            break;
        case 17:
        case 8:
            SetLEDColor(4,CRGB::Green);
            //SetLEDColor(5,CRGB::Green);
            break;
        case 18:
        case 7:
            SetLEDColor(6,CRGB::Green);
            //SetLEDColor(7,CRGB::Green);
            break;
        case 19:
        case 6:
            SetLEDColor(8,CRGB::Green);
           //SetLEDColor(9,CRGB::Green);
            break;
        case 20:
        case 11:
            SetLEDColor(10,CRGB::Green);
            //SetLEDColor(11,CRGB::Green);
            break;
    }
}

void SetLEDColorFromTagIdLeft(int tagId, CRGB color){
    switch(tagId){
        case 21:
        case 10:
            //SetLEDColor(0,CRGB::Green);
            SetLEDColor(1,CRGB::Green);
            break;
        case 22:
        case 9:
            //SetLEDColor(2,CRGB::Green);
            SetLEDColor(3,CRGB::Green);
            break;
        case 17:
        case 8:
            //SetLEDColor(4,CRGB::Green);
            SetLEDColor(5,CRGB::Green);
            break;
        case 18:
        case 7:
            //SetLEDColor(6,CRGB::Green);
            SetLEDColor(7,CRGB::Green);
            break;
        case 19:
        case 6:
            //SetLEDColor(8,CRGB::Green);
            SetLEDColor(9,CRGB::Green);
            break;
        case 20:
        case 11:
            //SetLEDColor(10,CRGB::Green);
            SetLEDColor(11,CRGB::Green);
            break;
    }
}


void SetupEthernet(){
    // Simple ethernet setup
    byte mac[6] = {0x02, 0xFE, 0xED, 0x65, 0x74, 0x64};
    Serial.println("Starting Ethernet...");
    
    if (Ethernet.begin(mac,5000)) {
        Serial.println("✅ Ethernet configured via DHCP");
    } else {
        // Try static IP
        IPAddress ip(10, 65, 74, 100);  // Team 6574 static IP
        IPAddress gateway(10, 65, 74, 4);
        IPAddress subnet(255, 255, 255, 0);
        Ethernet.begin(mac, ip, gateway, gateway, subnet);
        Serial.println("✅ Ethernet configured with static IP");
    }

    // Attempt DHCP with timeout
    unsigned long startTime = millis();
    unsigned long timeout = 5000; // 5 second timeout
    while (Ethernet.linkStatus() == LinkOFF) {
        if (millis() - startTime > timeout) {
        Serial.println("Ethernet cable not connected - continuing without network");
        break;
        }
        delay(100);
    }
    
    // Check if we got a connection
    if (Ethernet.linkStatus() == LinkON) {
        Serial.print("IP Address: ");
        Serial.println(Ethernet.localIP());
    } else {
        Serial.println("Running in offline mode");
    }
    
    Serial.print("Local IP: ");
    Serial.println(Ethernet.localIP());
}

void isr_animationTimer(){
    animationFrame = ++animationFrame % STATES_PER_LED; // Toggle frame 0 to STATES_PER_LED-1
}

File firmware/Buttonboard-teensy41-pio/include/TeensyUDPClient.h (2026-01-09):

/*
 * Teensy UDP Client - Simple Telemetry Receiver
 * 
 * Receives robot telemetry via UDP - MUCH simpler than NetworkTables!
 */

#ifndef TEENSY_UDP_CLIENT_H
#define TEENSY_UDP_CLIENT_H

#include <Arduino.h>
#include <NativeEthernet.h>
#include <EthernetUdp.h>
#include <ArduinoJson.h>

class TeensyUDPClient {
private:
    EthernetUDP udp;
    uint16_t localPort;
    IPAddress robotIP;
    int teamNumber;
    unsigned long lastPacketTime;
    int packetsReceived;
    
    // Discovery and heartbeat
    unsigned long lastDiscoveryTime;
    unsigned long discoveryInterval;
    bool robotKnowsAboutUs;
    
    // Robot telemetry data
    struct RobotData {
        double timestamp = 0.0;
        
        // Battery
        double batteryVoltage = 0.0;
        bool batteryIsLow = false;
        
        // Robot state
        bool robotEnabled = false;
        bool isAutonomous = false;
        bool isTeleop = false;
        String robotMode = "Unknown";
        
        // Alliance
        String allianceColor = "unknown";
        bool isRedAlliance = false;
        
        // Match
        double matchTimeRemaining = 0.0;
        
        // Subsystems
        bool shooterReady = false;
        int shooterSpeed = 0;
        bool intakeDeployed = false;
        double intakePosition = 0.0;
        
        // Auto
        String autoMode = "Unknown";
        int autoModeNumber = 0;
        
        // Status
        String statusMessage = "";
        int heartbeat = 0;
        
        unsigned long lastUpdate = 0;

        bool leftCamHasTag = false;
        float leftCamTagID=-1;
        bool rightCamHasTag = false;
        float rightCamTagID=-1;

        /**
         * Compare meaningful fields (ignore timestamp, heartbeat, lastUpdate)
         * Returns true if any significant data has changed
         */
        bool hasSignificantChanges(const RobotData& other) const {
            return (abs(batteryVoltage - other.batteryVoltage) > 0.01) ||
                   (batteryIsLow != other.batteryIsLow) ||
                   (robotEnabled != other.robotEnabled) ||
                   (isAutonomous != other.isAutonomous) ||
                   (isTeleop != other.isTeleop) ||
                   (robotMode != other.robotMode) ||
                   (allianceColor != other.allianceColor) ||
                   (isRedAlliance != other.isRedAlliance) ||
                   (abs(matchTimeRemaining - other.matchTimeRemaining) > 0.1) ||
                   (shooterReady != other.shooterReady) ||
                   (shooterSpeed != other.shooterSpeed) ||
                   (intakeDeployed != other.intakeDeployed) ||
                   (abs(intakePosition - other.intakePosition) > 0.01) ||
                   (autoMode != other.autoMode) ||
                   (autoModeNumber != other.autoModeNumber) ||
                   (statusMessage != other.statusMessage) ||
                   (leftCamHasTag != other.leftCamHasTag) ||
                   (leftCamTagID != other.leftCamTagID) ||
                   (rightCamHasTag != other.rightCamHasTag) ||
                   (rightCamTagID != other.rightCamTagID);
        }
        
        /**
         * Copy meaningful data from another RobotData (preserves timestamps)
         */
        void copySignificantData(const RobotData& source) {
            batteryVoltage = source.batteryVoltage;
            batteryIsLow = source.batteryIsLow;
            robotEnabled = source.robotEnabled;
            isAutonomous = source.isAutonomous;
            isTeleop = source.isTeleop;
            robotMode = source.robotMode;
            allianceColor = source.allianceColor;
            isRedAlliance = source.isRedAlliance;
            matchTimeRemaining = source.matchTimeRemaining;
            shooterReady = source.shooterReady;
            shooterSpeed = source.shooterSpeed;
            intakeDeployed = source.intakeDeployed;
            intakePosition = source.intakePosition;
            autoMode = source.autoMode;
            autoModeNumber = source.autoModeNumber;
            statusMessage = source.statusMessage;
            leftCamHasTag = source.leftCamHasTag;
            leftCamTagID = source.leftCamTagID;
            rightCamHasTag = source.rightCamHasTag;
            rightCamTagID = source.rightCamTagID;
        }
    } robotData;
    
    // Previous state for change detection
    RobotData previousRobotData;
    bool hasNewChangedData = false;
    
    IPAddress calculateRobotIP(int teamNumber) {
        if (teamNumber <= 0) return IPAddress(10, 0, 0, 2);
        int firstOctet = teamNumber / 100;
        int secondOctet = teamNumber % 100;
        return IPAddress(10, firstOctet, secondOctet, 2);
    }
    
    void debugPrint(const String& message) {
        Serial.println("UDP: " + message);
    }
    
    void sendDiscoveryMessage() {
        // Send "here I am" message to robot
        String discoveryMsg = "{\"type\":\"discovery\",\"device\":\"teensy_control_board\",\"ip\":\"";
        discoveryMsg += String(Ethernet.localIP()[0]) + "." + String(Ethernet.localIP()[1]) + "." + 
                       String(Ethernet.localIP()[2]) + "." + String(Ethernet.localIP()[3]);
        discoveryMsg += "\",\"port\":" + String(localPort);
        discoveryMsg += ",\"team\":" + String(teamNumber);
        discoveryMsg += ",\"timestamp\":" + String(millis());
        discoveryMsg += "}";
        
        // Send to robot's discovery port (robot should listen on multiple ports)
        udp.beginPacket(robotIP, 5575); // Discovery port
        udp.print(discoveryMsg);
        udp.endPacket();
        
        debugPrint("📡 Sent discovery: " + discoveryMsg);
    }
    
    void parseRobotData(const String& jsonData) {
        DynamicJsonDocument doc(1024);
        DeserializationError error = deserializeJson(doc, jsonData);
        
        if (error) {
            debugPrint("❌ JSON parse error: " + String(error.c_str()));
            return;
        }
        

        debugPrint(jsonData);
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

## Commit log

2025-06-29 led test and debounce sketch
2025-06-30 switched connectors to JST HX
    [carrierboard.brd]
2025-07-02 commit to more buttons
    [carrierboard.brd, carrierboard.sch]
2025-07-05 code for 4 more buttons and networktables
2025-07-08 pixel pin correction
2025-07-08 button mods
    [button.scad, buttonface.stl, cap.stl]
2025-07-08 archived arduino .ino project
2025-07-12 button tweaks and new printable buttons
    [ISOThread.scad, button.scad, buttonface thicker.stl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]
2025-07-12 button features and tweaks
    [button.scad, button.stl, housing.scad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]
2025-07-12 fins on housing and printability changes
    [button.stl, housing.scad, housing.stl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]
2025-07-14 a bit more yet
    [button.stl, nut.scad, nut.stl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]
2025-07-15 working project with buttons
2025-07-17 adjustments for new momentary switches, joystick button states for initial integration with robot
    [housing.stl, nut.scad, nut.stl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]
2025-07-17 simplified button housing
    [housing.scad]
2025-07-19 led cap tweaks
    [button.stl, housing.stl, nut.stl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]
2025-07-20 button groupings
2025-07-22 pretty initialization of leds
2025-07-26 updated button colors
2025-07-28 button color changes at MROC
2025-08-03 minor changes to dimensions for bambu p1s
    [housing.stl, ledcap.scad, ledcap.stl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]
2025-08-17 UDPServer works. Time to merge in buttons and lights again.
2025-08-18 warning if button pressed and not teleop
2025-08-18 less chatty driver station log
2025-08-19 match time and pdp voltage
2025-10-07 respond to tag messages, not working
    [TeensyUDPClient.h, main.cpp]
2025-10-12 catch up button changes
    [button.3mf, button.stl, housing.3mf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]
2025-10-13 trying like heck to not block when ethernet is unplugged
    [ISOThread.scad, button.scad, button.stl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]
2025-10-14 modularize lcd provision
    [chassis.scad]
2025-10-28 led caps 2mm higher
    [ledcap.scad, params.scad]
2025-10-28 printed them too
    [ledcap.3mf, ledcap.stl]

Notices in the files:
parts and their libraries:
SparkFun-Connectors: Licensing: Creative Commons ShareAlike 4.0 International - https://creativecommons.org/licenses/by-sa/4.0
